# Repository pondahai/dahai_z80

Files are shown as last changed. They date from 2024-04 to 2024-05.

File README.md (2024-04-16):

# dahai_z80  
## 快照  screenshot  
螢幕擷取畫面 2024-04-11 163721

螢幕擷取畫面 2024-04-11 163736

螢幕擷取畫面 2024-04-11 163752


## 參考來源  reference  
Z80微電腦製作，劉秋良，欣大出版  


4晶片的結合Z80與arduino的專案  
https://hackaday.io/project/19000-a-4-4ics-z80-homemade-computer-on-breadboard/details

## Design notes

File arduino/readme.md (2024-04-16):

這一隻arduino程式僅能在uno上執行  
因為用到底層暫存器的存取  

程式主要利用了攔截z80執行週期的方式  
將程式碼搬運到板上的SRAM  
隨後arduino放開對z80的控制  
並且利用arduino的內部計時器產生z80所需的時脈信號  
另外arduino也接收了z80的IORQ信號  
當z80程式執行到IN OUT指令時  
arduino可以充當z80系統的串列埠  
於是電腦端就可以透過串列終端機  
與Z80系統進行通訊

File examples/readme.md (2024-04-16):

這裡存放了本z80微電腦系統中預先安裝的幾隻範例程式  
分別是：
1. ABC-80監督程式
2. 圓周率計算程式
3. 迷你監督程式(透過串列埠)
4. BASIC

為了能夠在這一套z80系統中運作  
都有少許的修改  

感謝這些原作者的貢獻  
這是他們的智慧結晶

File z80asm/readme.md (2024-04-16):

這是z80的組譯器  
來自：http://www.trs-80emulators.com/z80asm/  
主要使用方法
```
z80asm.exe 原始碼 -cim
```
結果會產生 .lst 以及二進制檔 .cim  

另外 conv.py 這隻程式是用來把.cim檔轉換成c語言陣列變數格式  
以便用來把程式碼放在arduino程式裡面  
使用方法：
```
python3 conv.py 二進位碼檔.cim
```
他會直接輸出結果到標準輸出  
可以直接在命令列視窗中複製  
或者用轉向指令把結果存成檔案再進行後續處理

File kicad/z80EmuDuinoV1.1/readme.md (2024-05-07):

螢幕擷取畫面 2024-05-07 092956

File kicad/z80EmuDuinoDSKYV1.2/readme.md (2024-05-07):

螢幕擷取畫面 2024-05-07 092819

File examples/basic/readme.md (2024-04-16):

來自：  
http://searle.x10host.com/z80/SimpleZ80.html  
這個網站也是一套Z80微電腦系統  
裡面有用到一套培基語言  
我把它進行修改以符合本Z80系統的運作  
透過串列埠終端機的方式操作

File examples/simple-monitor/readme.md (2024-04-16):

來自：  
[https://github.com/skx/z80-examples/tree/master](https://github.com/skx/z80-examples/blob/master/simple-monitor.z80)

simple-monitor是一個簡易型透過終端機存取的監督程式  
是利用Z80的IN OUT指令對IO埠口讀寫以達到模擬串列埠的效果  
我有修改部分程式以便符合本套Z80微電腦的架構

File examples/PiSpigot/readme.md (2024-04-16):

這隻程式來自：  
https://github.com/GmEsoft/Z80-MBC2_PiSpigot?tab=readme-ov-file  
原本程式是透過IN OUT指令在另一部Z80微電腦上  
以終端機方式呈現程式運作結果  
我做了一些修改才能在這部Z80微電腦上執行

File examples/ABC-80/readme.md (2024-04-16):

這組程式來自書籍
```
書目資訊
書名	Z 80 微電腦入門: 原理與應用程式
作者	劉秋良
出版者	欣大, 1986
```
書中設計了一部Z80微電腦  
並且將運作其中的監督程式原始碼詳列在書中

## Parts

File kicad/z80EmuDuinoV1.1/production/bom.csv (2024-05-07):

Designator | Footprint | Quantity | Value | LCSC Part #
A1 | Arduino_UNO_R3 | 1 | Arduino_UNO_R3
C1, C2, C3, C4 | C_Disc_D5.0mm_W2.5mm_P5.00mm | 4 | 100n
D1 | LED_D5.0mm_Clear | 1 | HALT
H1, H2, H3, H4 | MountingHole_3.2mm_With_Spacer_H10mm | 4 | M3_Hole_With_Spacer_H10mm
J1 | PinHeader_1x08_P2.54mm_Vertical | 1 | PA
J2 | PinHeader_1x08_P2.54mm_Vertical | 1 | PB
J3 | PinHeader_1x08_P2.54mm_Vertical | 1 | PC
J4, J5, J6, J8 | PinSocket_1x08_P2.54mm_Vertical | 4 | Conn_01x08_Socket
J7 | PinSocket_1x03_P2.54mm_Vertical | 1 | DSKY_PWR
JP1 | TestPoint_2Pads_Pitch2.54mm_Drill0.8mm | 1 | 6264 VCC
JP2 | TestPoint_2Pads_Pitch2.54mm_Drill0.8mm | 1 | A17
JP3 | TestPoint_2Pads_Pitch2.54mm_Drill0.8mm | 1 | 62256 A14
JP4 | TestPoint_2Pads_Pitch2.54mm_Drill0.8mm | 1 | 62256 A13
JP5 | TestPoint_2Pads_Pitch2.54mm_Drill0.8mm | 1 | 6264 CE2
R2 | R_Axial_DIN0207_L6.3mm_D2.5mm_P10.16mm_Horizontal | 1 | 330
RN1, RN2, RN3, RN4 | R_Array_SIP9 | 4 | 10k
U1 | DIP-32_W15.24mm | 1 | AS6C4008-55PCN
U10 | DIP-40_W15.24mm_LongPads | 1 | Z80CPU
U11 | DIP-40_W15.24mm | 1 | 8255A
U2 | DIP-32_W7.62mm | 1 | AS6C4008-55PCN
U4 | DIP-14_W7.62mm_LongPads | 1 | 74LS32
U5 | DIP-14_W7.62mm_LongPads | 1 | 74LS00

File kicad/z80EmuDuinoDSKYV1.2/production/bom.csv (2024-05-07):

Designator | Footprint | Quantity | Value | LCSC Part #
BZ1 | Buzzer_TDK_PS1240P02BT_D12.2mm_H6.5mm | 1 | Buzzer
C1 | C_Disc_D5.0mm_W2.5mm_P5.00mm | 1 | 100n
C2, C3, C4 | C_Disc_D5.0mm_W2.5mm_P5.00mm | 3 | 20n
D1 | LED_D5.0mm_Clear | 1 | PC7
J1 | PinSocket_1x08_P2.54mm_Vertical | 1 | PB
J2 | PinSocket_1x08_P2.54mm_Vertical | 1 | PA
J3 | PinSocket_1x08_P2.54mm_Vertical | 1 | PC
J4 | PinSocket_1x08_P2.54mm_Vertical | 1 | KEYPAD
J5 | PinSocket_1x03_P2.54mm_Vertical | 1 | Conn_01x03_Pin
Q1, Q2, Q3, Q4, Q5, Q6 | TO-92_Inline | 6 | 2N3906
Q10, Q11, Q12, Q7, Q8, Q9 | TO-92_Inline | 6 | 2SA1015
R1, R2, R3, R4, R5, R6, R7, R8 | R_Axial_DIN0207_L6.3mm_D2.5mm_P10.16mm_Horizontal | 8 | 220
R10 | R_Axial_DIN0207_L6.3mm_D2.5mm_P10.16mm_Horizontal | 1 | R10
R11 | R_Axial_DIN0207_L6.3mm_D2.5mm_P10.16mm_Horizontal | 1 | R11
R12 | R_Axial_DIN0207_L6.3mm_D2.5mm_P10.16mm_Horizontal | 1 | Rf
R13, R14, R15 | R_Axial_DIN0207_L6.3mm_D2.5mm_P10.16mm_Horizontal | 3 | 10k
R16, R9 | R_Axial_DIN0207_L6.3mm_D2.5mm_P10.16mm_Horizontal | 2 | 330
RN1 | R_Array_SIP9 | 1 | 10k
SW1 | SW_Kailh_Choc_V1 | 1 | RESET
SW10 | SW_Kailh_Choc_V1 | 1 | 8
SW11 | SW_Kailh_Choc_V1 | 1 | 4
SW12 | SW_Kailh_Choc_V1 | 1 | 0
SW13 | SW_Kailh_Choc_V1 | 1 | D
SW14 | SW_Kailh_Choc_V1 | 1 | 9
SW15 | SW_Kailh_Choc_V1 | 1 | 5
SW16 | SW_Kailh_Choc_V1 | 1 | 1
SW17 | SW_Kailh_Choc_V1 | 1 | E
SW18 | SW_Kailh_Choc_V1 | 1 | A
SW19 | SW_Kailh_Choc_V1 | 1 | 6
SW2 | SW_Kailh_Choc_V1 | 1 | TO TAPE
SW20 | SW_Kailh_Choc_V1 | 1 | 2
SW21 | SW_Kailh_Choc_V1 | 1 | F
SW22 | SW_Kailh_Choc_V1 | 1 | B
SW23 | SW_Kailh_Choc_V1 | 1 | 7
SW24 | SW_Kailh_Choc_V1 | 1 | 3
SW3 | SW_Kailh_Choc_V1 | 1 | FROM TAPE
SW4 | SW_Kailh_Choc_V1 | 1 | GO
SW5 | SW_Kailh_Choc_V1 | 1 | ADDR
SW6 | SW_Kailh_Choc_V1 | 1 | DATA
SW7 | SW_Kailh_Choc_V1 | 1 | -
SW8 | SW_Kailh_Choc_V1 | 1 | +
SW9 | SW_Kailh_Choc_V1 | 1 | C
TP1 | PinHeader_1x01_P2.54mm_Vertical | 1 | AUDIO OUT
TP2 | PinHeader_1x01_P2.54mm_Vertical | 1 | AUDIO IN
TP3, TP4 | PinHeader_1x01_P2.54mm_Vertical | 2 | GND
U1, U2 | D1X8K | 2 | D148K
U3 | CA56-12EWA | 1 | CC56-12EWA
U4 | DIP-8_W7.62mm_LongPads | 1 | MCP6002-xP

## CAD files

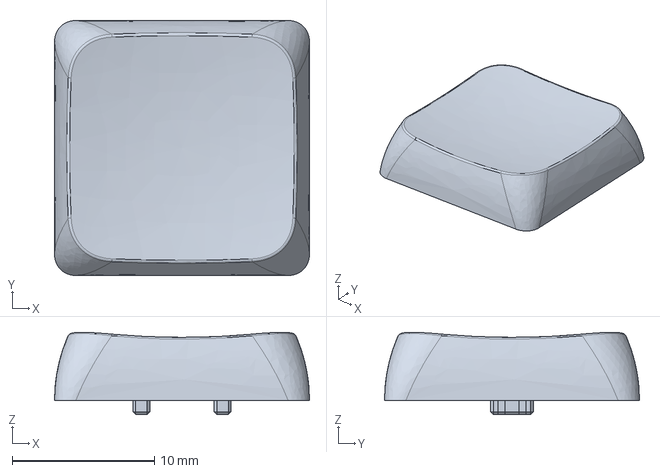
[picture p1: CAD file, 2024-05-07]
kicad/z80EmuDuinoDSKYV1.2/Kailh Choc FunkMonk 1u_black.step
17.9 x 17.9 x 5.78 mm

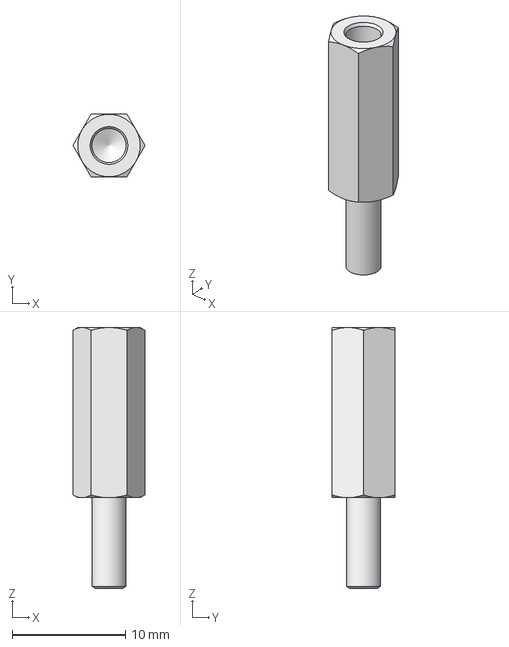
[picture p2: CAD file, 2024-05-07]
kicad/z80EmuDuinoV1.1/hexagonal_spacer_MF_M3_H15_HEX5.5_FTD8_MTL8.step
6.36 x 5.51 x 23.0 mm

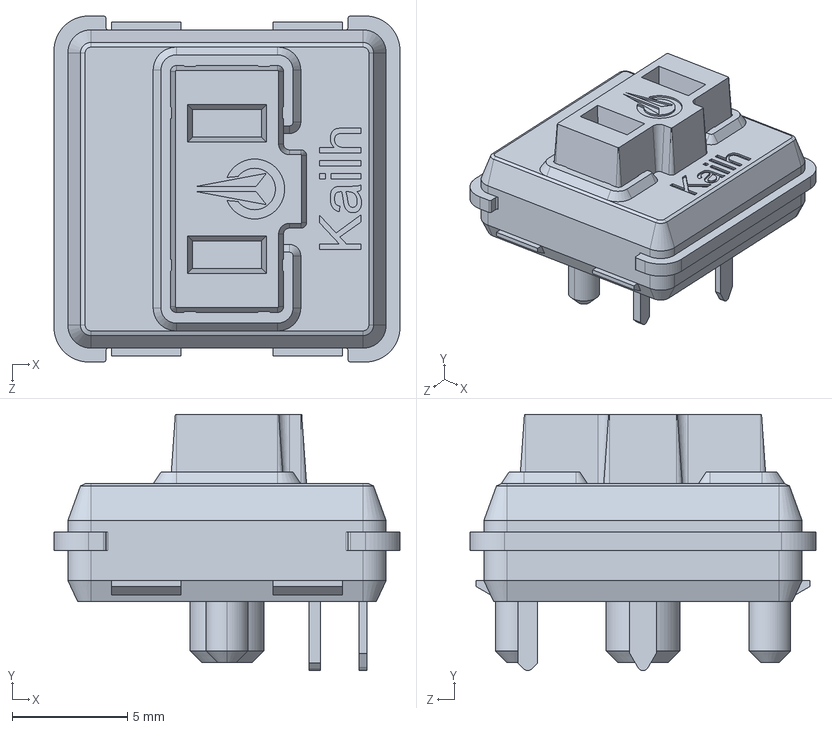
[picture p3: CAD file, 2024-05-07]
kicad/z80EmuDuinoDSKYV1.2/Kailh LP Choc Burnt Orange.STEP
15.0 x 11.1 x 15.0 mm

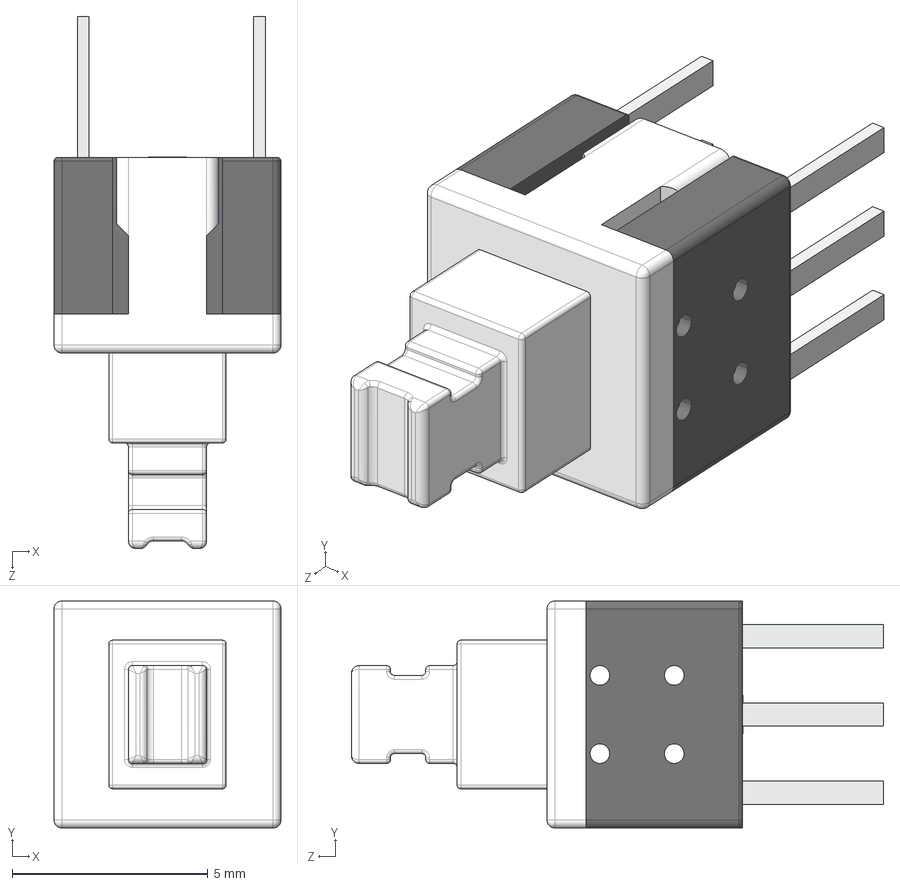
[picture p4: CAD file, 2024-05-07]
kicad/z80EmuDuinoDSKYV1.2/5.8x5.8mmSWITCH.STEP
5.80 x 5.80 x 13.6 mm

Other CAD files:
kicad/z80EmuDuinoDSKYV1.2/Kailh Choc FunkMonk 1u.step

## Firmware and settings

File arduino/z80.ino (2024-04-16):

#include <TimeLib.h>

#define CS328 2
#define nRD 3
#define Z80nRESET 4
#define RESET8255 5
#define nWAITrelease 6
#define ZA0 7
#define nWR 10
#define Z80CLK 11
#define ZA1 12
#define RAMCEINHIBIT 13

const byte intmini[] PROGMEM = {
0xf3, 0xc3, 0xb2, 0x00, 0x00, 0x00, 0x00, 0x00, 0xc3, 0xa2, 0x00, 0x00, 0x00, 0x00, 0x00, 0x00,
0xc3, 0x74, 0x00, 0x00, 0x00, 0x00, 0x00, 0x00, 0xc3, 0xa5, 0x00, 0x00, 0x00, 0x00, 0x00, 0x00,
0x00, 0x00, 0x00, 0x00, 0x00, 0x00, 0x00, 0x00, 0x00, 0x00, 0x00, 0x00, 0x00, 0x00, 0x00, 0x00,
0x00, 0x00, 0x00, 0x00, 0x00, 0x00, 0x00, 0x00, 0x18, 0x00, 0xf5, 0xe5, 0xdb, 0x02, 0xe6, 0x02,
0x28, 0x2d, 0xdb, 0x01, 0xf5, 0x3a, 0x43, 0x20, 0xfe, 0x3f, 0x20, 0x03, 0xf1, 0x18, 0x20, 0x2a,
0x3f, 0x20, 0x23, 0x7d, 0xfe, 0x3f, 0x20, 0x03, 0x21, 0x00, 0x20, 0x22, 0x3f, 0x20, 0xf1, 0x77,
0x3a, 0x43, 0x20, 0x3c, 0x32, 0x43, 0x20, 0xfe, 0x30, 0x38, 0x04, 0x3e, 0xd6, 0xd3, 0x02, 0xe1,
0xf1, 0xfb, 0xed, 0x4d, 0xdb, 0x01, 0xc9, 0x3a, 0x43, 0x20, 0xfe, 0x00, 0x28, 0xf9, 0xe5, 0x2a,
0x41, 0x20, 0x23, 0x7d, 0xfe, 0x3f, 0x20, 0x03, 0x21, 0x00, 0x20, 0xf3, 0x22, 0x41, 0x20, 0x3a,
0x43, 0x20, 0x3d, 0x32, 0x43, 0x20, 0xfe, 0x05, 0x30, 0x04, 0x3e, 0x96, 0xd3, 0x02, 0x7e, 0xfb,
0xe1, 0xc9, 0xd3, 0x01, 0xc9, 0xdb, 0x02, 0xfe, 0x00, 0xc9, 0x7e, 0xb7, 0xc8, 0xcf, 0x23, 0x18,
0xf9, 0xc9, 0x21, 0xed, 0x20, 0xf9, 0x21, 0x00, 0x20, 0x22, 0x3f, 0x20, 0x22, 0x41, 0x20, 0xaf,
0x32, 0x43, 0x20, 0x3e, 0x96, 0xd3, 0x02, 0xed, 0x56, 0xfb, 0x21, 0x03, 0x01, 0xcd, 0xaa, 0x00,
0x3a, 0x44, 0x20, 0xfe, 0x59, 0x20, 0x16, 0x21, 0x1e, 0x01, 0xcd, 0xaa, 0x00, 0xcd, 0x74, 0x00,
0xe6, 0xdf, 0xfe, 0x43, 0x20, 0x0f, 0xcf, 0x3e, 0x0d, 0xcf, 0x3e, 0x0a, 0xcf, 0x3e, 0x59, 0x32,
0x44, 0x20, 0xc3, 0x50, 0x01, 0xfe, 0x57, 0x20, 0xe4, 0xcf, 0x3e, 0x0d, 0xcf, 0x3e, 0x0a, 0xcf,
0xc3, 0x53, 0x01, 0x0c, 0x5a, 0x38, 0x30, 0x20, 0x53, 0x42, 0x43, 0x20, 0x42, 0x79, 0x20, 0x47,
0x72, 0x61, 0x6e, 0x74, 0x20, 0x53, 0x65, 0x61, 0x72, 0x6c, 0x65, 0x0d, 0x0a, 0x00, 0x0d, 0x0a,
0x43, 0x6f, 0x6c, 0x64, 0x20, 0x6f, 0x72, 0x20, 0x77, 0x61, 0x72, 0x6d, 0x20, 0x73, 0x74, 0x61,
0x72, 0x74, 0x20, 0x28, 0x43, 0x20, 0x6f, 0x72, 0x20, 0x57, 0x29, 0x3f, 0x20,

};

const byte basic4[] PROGMEM = {
0xc3, 0x56, 0x01, 0xc3, 0xf4, 0x01, 0xdd, 0x21, 0x00, 0x00, 0xc3, 0x61, 0x01, 0x0c, 0x0a, 0x82,
0x11, 0x21, 0x45, 0x20, 0xf9, 0xc3, 0xa1, 0x1d, 0x11, 0x33, 0x04, 0x06, 0x63, 0x21, 0x45, 0x20,
0x1a, 0x77, 0x23, 0x13, 0x05, 0xc2, 0x70, 0x01, 0xf9, 0xcd, 0x34, 0x06, 0xcd, 0x02, 0x0c, 0x32,
0xef, 0x20, 0x32, 0x3e, 0x21, 0x21, 0x48, 0x02, 0xcd, 0xa0, 0x12, 0xcd, 0x51, 0x06, 0xcd, 0x5a,
0x09, 0xb7, 0xc2, 0xaa, 0x01, 0x21, 0xa2, 0x21, 0x23, 0x7c, 0xb5, 0xca, 0xbc, 0x01, 0x7e, 0x47,
0x2f, 0x77, 0xbe, 0x70, 0xca, 0x98, 0x01, 0xc3, 0xbc, 0x01, 0xcd, 0x26, 0x0a, 0xb7, 0xc2, 0x02,
0x05, 0xeb, 0x2b, 0x3e, 0xd9, 0x46, 0x77, 0xbe, 0x70, 0xc2, 0x85, 0x01, 0x2b, 0x11, 0xa1, 0x21,
0xcd, 0xca, 0x07, 0xda, 0x85, 0x01, 0x11, 0xce, 0xff, 0x22, 0xf4, 0x20, 0x19, 0x22, 0x9f, 0x20,
0xcd, 0x0f, 0x06, 0x2a, 0x9f, 0x20, 0x11, 0xef, 0xff, 0x19, 0x11, 0x3e, 0x21, 0x7d, 0x93, 0x6f,
0x7c, 0x9a, 0x67, 0xe5, 0x21, 0x0c, 0x02, 0xcd, 0xa0, 0x12, 0xe1, 0xcd, 0x43, 0x19, 0x21, 0xfd,
0x01, 0xcd, 0xa0, 0x12, 0x31, 0xab, 0x20, 0xcd, 0x34, 0x06, 0xc3, 0x4d, 0x05, 0x20, 0x42, 0x79,
0x74, 0x65, 0x73, 0x20, 0x66, 0x72, 0x65, 0x65, 0x0d, 0x0a, 0x00, 0x00, 0x5a, 0x38, 0x30, 0x20,
0x42, 0x41, 0x53, 0x49, 0x43, 0x20, 0x56, 0x65, 0x72, 0x20, 0x34, 0x2e, 0x37, 0x62, 0x0d, 0x0a,
0x43, 0x6f, 0x70, 0x79, 0x72, 0x69, 0x67, 0x68, 0x74, 0x20, 0x22, 0x2c, 0x34, 0x30, 0x2c, 0x22,
0x43, 0x29, 0x20, 0x31, 0x39, 0x37, 0x38, 0x20, 0x62, 0x79, 0x20, 0x4d, 0x69, 0x63, 0x72, 0x6f,
0x73, 0x6f, 0x66, 0x74, 0x0d, 0x0a, 0x00, 0x00, 0x4d, 0x65, 0x6d, 0x6f, 0x72, 0x79, 0x20, 0x74,
0x6f, 0x70, 0x00, 0xb8, 0x17, 0x7c, 0x18, 0xce, 0x17, 0x48, 0x20, 0x60, 0x11, 0xe5, 0x14, 0x8e,
0x11, 0x42, 0x1a, 0x21, 0x1b, 0x5d, 0x16, 0x90, 0x1a, 0x96, 0x1b, 0x9c, 0x1b, 0xfd, 0x1b, 0x12,
0x1c, 0x39, 0x15, 0x7d, 0x1c, 0x96, 0x20, 0x12, 0x14, 0x2a, 0x12, 0xac, 0x14, 0x21, 0x14, 0x32,
0x14, 0x9f, 0x1c, 0x32, 0x1d, 0x42, 0x14, 0x72, 0x14, 0x7c, 0x14, 0xc5, 0x4e, 0x44, 0xc6, 0x4f,
0x52, 0xce, 0x45, 0x58, 0x54, 0xc4, 0x41, 0x54, 0x41, 0xc9, 0x4e, 0x50, 0x55, 0x54, 0xc4, 0x49,
0x4d, 0xd2, 0x45, 0x41, 0x44, 0xcc, 0x45, 0x54, 0xc7, 0x4f, 0x54, 0x4f, 0xd2, 0x55, 0x4e, 0xc9,
0x46, 0xd2, 0x45, 0x53, 0x54, 0x4f, 0x52, 0x45, 0xc7, 0x4f, 0x53, 0x55, 0x42, 0xd2, 0x45, 0x54,
0x55, 0x52, 0x4e, 0xd2, 0x45, 0x4d, 0xd3, 0x54, 0x4f, 0x50, 0xcf, 0x55, 0x54, 0xcf, 0x4e, 0xce,
0x55, 0x4c, 0x4c, 0xd7, 0x41, 0x49, 0x54, 0xc4, 0x45, 0x46, 0xd0, 0x4f, 0x4b, 0x45, 0xc4, 0x4f,
0x4b, 0x45, 0xd3, 0x43, 0x52, 0x45, 0x45, 0x4e, 0xcc, 0x49, 0x4e, 0x45, 0x53, 0xc3, 0x4c, 0x53,
0xd7, 0x49, 0x44, 0x54, 0x48, 0xcd, 0x4f, 0x4e, 0x49, 0x54, 0x4f, 0x52, 0xd3, 0x45, 0x54, 0xd2,
0x45, 0x53, 0x45, 0x54, 0xd0, 0x52, 0x49, 0x4e, 0x54, 0xc3, 0x4f, 0x4e, 0x54, 0xcc, 0x49, 0x53,
0x54, 0xc3, 0x4c, 0x45, 0x41, 0x52, 0xc3, 0x4c, 0x4f, 0x41, 0x44, 0xc3, 0x53, 0x41, 0x56, 0x45,
0xce, 0x45, 0x57, 0xd4, 0x41, 0x42, 0x28, 0xd4, 0x4f, 0xc6, 0x4e, 0xd3, 0x50, 0x43, 0x28, 0xd4,
0x48, 0x45, 0x4e, 0xce, 0x4f, 0x54, 0xd3, 0x54, 0x45, 0x50, 0xab, 0xad, 0xaa, 0xaf, 0xde, 0xc1,
0x4e, 0x44, 0xcf, 0x52, 0xbe, 0xbd, 0xbc, 0xd3, 0x47, 0x4e, 0xc9, 0x4e, 0x54, 0xc1, 0x42, 0x53,
0xd5, 0x53, 0x52, 0xc6, 0x52, 0x45, 0xc9, 0x4e, 0x50, 0xd0, 0x4f, 0x53, 0xd3, 0x51, 0x52, 0xd2,
0x4e, 0x44, 0xcc, 0x4f, 0x47, 0xc5, 0x58, 0x50, 0xc3, 0x4f, 0x53, 0xd3, 0x49, 0x4e, 0xd4, 0x41,
0x4e, 0xc1, 0x54, 0x4e, 0xd0, 0x45, 0x45, 0x4b, 0xc4, 0x45, 0x45, 0x4b, 0xd0, 0x4f, 0x49, 0x4e,
0x54, 0xcc, 0x45, 0x4e, 0xd3, 0x54, 0x52, 0x24, 0xd6, 0x41, 0x4c, 0xc1, 0x53, 0x43, 0xc3, 0x48,
0x52, 0x24, 0xc8, 0x45, 0x58, 0x24, 0xc2, 0x49, 0x4e, 0x24, 0xcc, 0x45, 0x46, 0x54, 0x24, 0xd2,
0x49, 0x47, 0x48, 0x54, 0x24, 0xcd, 0x49, 0x44, 0x24, 0x80, 0xa4, 0x09, 0xa1, 0x08, 0x7c, 0x0d,
0xf1, 0x0a, 0x83, 0x0c, 0xb8, 0x0f, 0xb2, 0x0c, 0x08, 0x0b, 0xae, 0x0a, 0x91, 0x0a, 0x80, 0x0b,
0x6a, 0x09, 0x9d, 0x0a, 0xcc, 0x0a, 0xf3, 0x0a, 0xa2, 0x09, 0xf1, 0x14, 0x62, 0x0b, 0xe3, 0x09,
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

};

const byte monitor4[] PROGMEM = {
  // 0x3e, 0x90, 0xd3, 0x83, 0x3e, 0xff, 0xd3, 0x82, 0x3e, 0x00, 0xd3, 0x82, 0xc3, 0x00, 0x00
  // 0x3e, 0x90, 0xd3, 0x83, 0x3e, 0x00, 0xd3, 0x82, 0xdb, 0x80, 0xd3, 0x81, 0xc3, 0x00, 0x00

  0x31, 0x3e, 0x00, 0x3e, 0x3e, 0xd3, 0x01, 0x21, 0x3e, 0x00, 0x36, 0x10, 0xdb, 0x01, 0x77, 0xfe,
  0x10, 0x28, 0x03, 0x23, 0x18, 0xf4, 0x21, 0x3e, 0x00, 0x7e, 0x3e, 0x45, 0xd3, 0x01, 0x3e, 0x52,
  0xd3, 0x01, 0xd3, 0x01, 0x3e, 0x10, 0xd3, 0x01, 0x18, 0xd9, 0x00, 0x00, 0x00, 0x00, 0x00, 0x00,
  0x00, 0x00, 0x00, 0x00, 0x00, 0x00, 0x00, 0x00, 0x00, 0x00, 0x00, 0x00, 0x00, 0x00,

  // 0x3e, 0x31, 0xd3, 0x01, 0x3e, 0x32, 0xd3, 0x01, 0x3e, 0x0d, 0xd3, 0x01,
  // 0xdb, 0x01, 0x00, 0x00, 0x00, 0xd3, 0x01, 0xc3, 0x0c, 0x00, 0x00, 0xc3, 0x0c, 0x00

  // 0xc3, 0x00, 0x20
};
// tiny BASIC
const byte basic[] PROGMEM = {

};

// simple-monitor
const byte simple_monitor[] PROGMEM = {
0x31, 0x17, 0x01, 0x3e, 0x3e, 0xd3, 0x01, 0x21, 0x17, 0x01, 0x36, 0x0a, 0xdb, 0x01, 0x77, 0xd3,
0x01, 0xfe, 0x0d, 0x28, 0x03, 0x23, 0x18, 0xf2, 0x21, 0x17, 0x01, 0x7e, 0xfe, 0x63, 0x28, 0x28,
0xfe, 0x43, 0x28, 0x24, 0xfe, 0x64, 0x28, 0x2c, 0xfe, 0x44, 0x28, 0x28, 0xfe, 0x69, 0x28, 0x53,
0xfe, 0x49, 0x28, 0x4f, 0x3e, 0x45, 0xd3, 0x01, 0x3e, 0x52, 0xd3, 0x01, 0xd3, 0x01, 0x3e, 0x0d,
0xd3, 0x01, 0x3e, 0x0a, 0xd3, 0x01, 0x18, 0xbb, 0x21, 0x18, 0x01, 0xcd, 0xac, 0x00, 0x21, 0x03,
0x00, 0xe5, 0xc5, 0xc9, 0x21, 0x18, 0x01, 0x7e, 0xfe, 0x0d, 0x28, 0x07, 0xcd, 0xac, 0x00, 0xed,
0x43, 0xff, 0x00, 0x2a, 0xff, 0x00, 0xcd, 0xe2, 0x00, 0x06, 0x10, 0x3e, 0x20, 0xd3, 0x01, 0x4e,
0xcd, 0xeb, 0x00, 0x23, 0x10, 0xf5, 0x3e, 0x0d, 0xd3, 0x01, 0x3e, 0x0a, 0xd3, 0x01, 0x22, 0xff,
0x00, 0x18, 0x80, 0x21, 0x18, 0x01, 0x7e, 0xfe, 0x20, 0x28, 0x07, 0xcd, 0xac, 0x00, 0xed, 0x43,
0x01, 0x01, 0x7e, 0x23, 0xfe, 0x20, 0x28, 0xfa, 0xfe, 0x0d, 0x28, 0xe5, 0x2b, 0xcd, 0xb5, 0x00,
0xed, 0x4b, 0x01, 0x01, 0x02, 0x03, 0xed, 0x43, 0x01, 0x01, 0x18, 0xe6, 0xcd, 0xb5, 0x00, 0x47,
0xcd, 0xb5, 0x00, 0x4f, 0xc9, 0x7e, 0xfe, 0x61, 0x38, 0x06, 0xfe, 0x7a, 0x30, 0x02, 0xd6, 0x20,
0xcd, 0xda, 0x00, 0x87, 0x87, 0x87, 0x87, 0x57, 0x23, 0x7e, 0xfe, 0x61, 0x38, 0x06, 0xfe, 0x7a,
0x30, 0x02, 0xd6, 0x20, 0xcd, 0xda, 0x00, 0xb2, 0x23, 0xc9, 0xd6, 0x30, 0xfe, 0x0a, 0xd8, 0xd6,
0x07, 0xc9, 0x4c, 0xcd, 0xeb, 0x00, 0x4d, 0xcd, 0xeb, 0x00, 0xc9, 0x79, 0x1f, 0x1f, 0x1f, 0x1f,
0xcd, 0xf4, 0x00, 0x79, 0xe6, 0x0f, 0xc6, 0x90, 0x27, 0xce, 0x40, 0x27, 0xd3, 0x01, 0xc9, 0x00,
0x00, 0x00, 0x00, 0x00, 0x00, 0x00, 0x00, 0x00, 0x00, 0x00, 0x00, 0x00, 0x00, 0x00, 0x00, 0x00,
0x00, 0x00, 0x00, 0x00, 0x00, 0x00,

};


const byte pi_calcu[] PROGMEM = {
0xf3, 0xc3, 0xd2, 0x01, 0x08, 0x3e, 0x01, 0xd3, 0x00, 0x08, 0xd3, 0x01, 0xc9, 0x7e, 0x23, 0xb7,
0xc8, 0xcd, 0x04, 0x00, 0x18, 0xf7, 0x11, 0xe8, 0x03, 0xcd, 0x2b, 0x00, 0x11, 0x64, 0x00, 0xcd,
0x2b, 0x00, 0x11, 0x0a, 0x00, 0xcd, 0x2b, 0x00, 0x7d, 0x18, 0x08, 0x3e, 0xff, 0x3c, 0xed, 0x52,
0x30, 0xfb, 0x19, 0xc6, 0x30, 0x18, 0xcd, 0x06, 0x0a, 0xcd, 0x40, 0x00, 0xc6, 0x30, 0x18, 0xc4,
0x0e, 0xff, 0x0c, 0x90, 0x30, 0xfc, 0x80, 0x47, 0x79, 0xcd, 0x3c, 0x00, 0x78, 0xc9, 0x23, 0x23,
0x3e, 0x84, 0xd3, 0x00, 0xdb, 0x00, 0x77, 0x2b, 0xdb, 0x00, 0x77, 0x2b, 0xdb, 0x00, 0x77, 0xc9,
0x7e, 0x23, 0xcd, 0x37, 0x00, 0x3e, 0x3a, 0xcd, 0x04, 0x00, 0x7e, 0x23, 0xcd, 0x37, 0x00, 0x3e,
0x3a, 0xcd, 0x04, 0x00, 0x7e, 0xc3, 0x37, 0x00, 0xdb, 0x01, 0xfe, 0xff, 0x28, 0xfa, 0xc9, 0xaf,
0xeb, 0x3c, 0xc8, 0x29, 0x30, 0xfb, 0xcb, 0x1c, 0xcb, 0x1d, 0x44, 0x4d, 0xeb, 0x11, 0x00, 0x00,
0xeb, 0x29, 0xeb, 0xed, 0x42, 0x13, 0x30, 0x02, 0x1b, 0x09, 0xcb, 0x38, 0xcb, 0x19, 0x3d, 0x20,
0xef, 0xeb, 0xc9, 0x06, 0x04, 0xeb, 0xd9, 0xeb, 0x7a, 0xb7, 0x7b, 0xd9, 0x20, 0x09, 0x05, 0xb7,
0x20, 0x05, 0x05, 0xb2, 0x20, 0x01, 0x05, 0x78, 0x87, 0x87, 0x87, 0x47, 0xaf, 0x05, 0x28, 0x09,
0x3c, 0xc8, 0x29, 0xd9, 0xed, 0x6a, 0xd9, 0x30, 0xf4, 0xd9, 0xcb, 0x1c, 0xcb, 0x1d, 0x44, 0x4d,
0xeb, 0x11, 0x00, 0x00, 0xd9, 0xcb, 0x1c, 0xcb, 0x1d, 0x44, 0x4d, 0xeb, 0x11, 0x00, 0x00, 0xeb,
0x29, 0xeb, 0xd9, 0xeb, 0xed, 0x6a, 0xeb, 0xd9, 0xed, 0x42, 0xd9, 0xed, 0x42, 0xd9, 0x13, 0x30,
0x06, 0x1b, 0x09, 0xd9, 0xed, 0x4a, 0xd9, 0xd9, 0xcb, 0x38, 0xcb, 0x19, 0xd9, 0xcb, 0x18, 0xcb,
0x19, 0x3d, 0x20, 0xdb, 0xeb, 0xd9, 0xeb, 0xd9, 0xc9, 0xcd, 0x30, 0x01, 0x21, 0x00, 0x00, 0xd9,
0x21, 0x00, 0x00, 0xd9, 0x3e, 0x10, 0xd9, 0xcb, 0x38, 0xcb, 0x19, 0xd9, 0xcb, 0x18, 0xcb, 0x19,
0xdc, 0x3d, 0x01, 0xeb, 0x29, 0xeb, 0xd9, 0xeb, 0xed, 0x6a, 0xeb, 0xd9, 0x3d, 0x20, 0xe7, 0xc9,
0x44, 0x4d, 0xd9, 0x44, 0x4d, 0xd9, 0xc9, 0x09, 0xd9, 0xed, 0x4a, 0xd9, 0xc9, 0x19, 0xd9, 0xed,
0x5a, 0xd9, 0xc9, 0x29, 0xd9, 0xed, 0x6a, 0xd9, 0xc9, 0xcd, 0x30, 0x01, 0xcd, 0x43, 0x01, 0xcd,
0x43, 0x01, 0xcd, 0x37, 0x01, 0xcd, 0x43, 0x01, 0xc9, 0xcd, 0x49, 0x01, 0xcd, 0xa3, 0x00, 0x01,
0x10, 0x00, 0x09, 0x22, 0x7a, 0x03, 0xeb, 0x2a, 0x78, 0x03, 0xb7, 0xed, 0x52, 0xeb, 0x30, 0x03,
0x2a, 0x78, 0x03, 0x22, 0x7a, 0x03, 0x29, 0x11, 0x8a, 0x03, 0x19, 0xe5, 0xdd, 0xe1, 0x21, 0x00,
0x00, 0x22, 0x7e, 0x03, 0x2a, 0x7e, 0x03, 0xed, 0x5b, 0x7a, 0x03, 0xd9, 0x21, 0x00, 0x00, 0x11,
0x00, 0x00, 0xd9, 0xcd, 0x09, 0x01, 0xeb, 0xdd, 0x6e, 0x00, 0xdd, 0x66, 0x01, 0xd9, 0xeb, 0x21,
0x00, 0x00, 0xd9, 0xcd, 0x49, 0x01, 0xcd, 0x3d, 0x01, 0xe5, 0x2a, 0x7a, 0x03, 0x29, 0x2b, 0xeb,
0xe1, 0xd9, 0x11, 0x00, 0x00, 0xd9, 0xcd, 0xa3, 0x00, 0x22, 0x7e, 0x03, 0xdd, 0x73, 0x00, 0xdd,
0x72, 0x01, 0xdd, 0x2b, 0xdd, 0x2b, 0x2a, 0x7a, 0x03, 0x2b, 0x22, 0x7a, 0x03, 0x7c, 0xb5, 0x20,
0xb3, 0xc9, 0x21, 0x2d, 0x03, 0xcd, 0x0d, 0x00, 0x21, 0x87, 0x03, 0xcd, 0x4e, 0x00, 0xfd, 0x21,
0x76, 0x03, 0x21, 0x32, 0x00, 0x23, 0x22, 0x76, 0x03, 0x11, 0x03, 0x00, 0xd9, 0x21, 0x00, 0x00,
0x11, 0x00, 0x00, 0xd9, 0xcd, 0x49, 0x01, 0xcd, 0xa3, 0x00, 0x22, 0x78, 0x03, 0x23, 0x44, 0x4d,
0x29, 0x11, 0x8a, 0x03, 0x19, 0xd9, 0x21, 0x00, 0x00, 0x39, 0xd9, 0xf9, 0x11, 0x02, 0x00, 0xd5,
0x0b, 0x78, 0xb1, 0x20, 0xfa, 0xd9, 0xf9, 0xaf, 0xfd, 0x77, 0x0a, 0xfd, 0x77, 0x0b, 0xfd, 0x36,
0x0e, 0x0a, 0xfd, 0x36, 0x0d, 0x06, 0xfd, 0x36, 0x0c, 0x2e, 0x21, 0x00, 0x00, 0x22, 0x7c, 0x03,
0x2b, 0x22, 0x85, 0x03, 0x2a, 0x7c, 0x03, 0xeb, 0x2a, 0x76, 0x03, 0xb7, 0xed, 0x52, 0x11, 0x03,
0x00, 0xd9, 0x21, 0x00, 0x00, 0x11, 0x00, 0x00, 0xd9, 0xcd, 0x59, 0x01, 0x2a, 0x7e, 0x03, 0x11,
0x0a, 0x00, 0xcd, 0x7f, 0x00, 0xed, 0x53, 0x8c, 0x03, 0x7d, 0xfe, 0x09, 0x20, 0x05, 0xfd, 0x34,
0x0a, 0x18, 0x3f, 0xfe, 0x0a, 0x20, 0x1c, 0xfd, 0x7e, 0x0b, 0xfd, 0x36, 0x0b, 0x00, 0x3c, 0xcd,
0xee, 0x02, 0xfd, 0x7e, 0x0a, 0xb7, 0x28, 0x09, 0xaf, 0xcd, 0xee, 0x02, 0xfd, 0x35, 0x0a, 0x20,
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

};
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
void loop() {
  // put your main code here, to run repeatedly:
  // delay(000);

  // digitalWrite(Z80CLK, HIGH); /*delay(000);*/ digitalWrite(Z80CLK, LOW);
  /*delay(000);*/
  // Serial.println();
  // CS328 and nWR
  if (((PIND & B00000100) == B00000000) && ((PINB & B00000100) == B00000000)) {

    // delay(1);
    int receive_char;
    // A0 == 0 A1 == 0
    if (((PIND & B10000000) == B00000000) && ((PINB & B00010000) == B00000000)) {
      delay(1);
      receive_char = (PINC & 0x3f | ((PINB & 0x03) << 6));
      if (receive_char == 0x84) {
        cmd_gettime = 1;
        // Serial.println("0x84");
      }
      // delay(1000);
      // digitalWrite(nWAITrelease, LOW);
      // stop timer
      TCCR2A = 0;
      TCCR2B = 0;
      Z80CLKSTROBE;
      PORTD = PORTD & ~B01000000;  // nWAIT release
      Z80CLKSTROBE;                // Tw
      Z80CLKSTROBE;                // T3

      // fetch cycle
      Z80CLKSTROBE;  // T1
      Z80CLKSTROBE;  // T2
      Z80CLKSTROBE;  // T3
      Z80CLKSTROBE;  // T4

      // while((PIND&B00000100) == B00000000);
      // while((PINB&B00000100) == B00000000);
      // digitalWrite(nWAITrelease, HIGH);
      PORTD = PORTD | B01000000;


      // delay(2);
      // restart timer
      TCCR2A = _BV(COM2A0) | _BV(COM2B1) | _BV(WGM21) | _BV(WGM20);
      TCCR2B = _BV(WGM22) | _BV(CS20);
    } // A0 == 0 A1 == 0
    // if(digitalRead(ZA0)==0 && digitalRead(ZA1)==0){
    // A0 == 1 A1 == 0
    else if (((PIND & B10000000) == B10000000) && ((PINB & B00010000) == B00000000)) {
      delay(1);
      receive_char = (PINC & 0x3f | ((PINB & 0x03) << 6));
      // Serial.print(receive_char, HEX); Serial.print(" ");


      Serial.write(receive_char);  // Serial.println();

      // delay(1000);
      // digitalWrite(nWAITrelease, LOW);
      // stop timer
      TCCR2A = 0;
      TCCR2B = 0;
      Z80CLKSTROBE;
      PORTD = PORTD & ~B01000000;  // nWAIT release
      Z80CLKSTROBE;                // Tw
      Z80CLKSTROBE;                // T3

      // fetch cycle
      Z80CLKSTROBE;  // T1
      Z80CLKSTROBE;  // T2
      Z80CLKSTROBE;  // T3
      Z80CLKSTROBE;  // T4

      // digitalWrite(nWAITrelease, HIGH);
      PORTD = PORTD | B01000000;


      // delay(2);
      // restart timer
      TCCR2A = _BV(COM2A0) | _BV(COM2B1) | _BV(WGM21) | _BV(WGM20);
      TCCR2B = _BV(WGM22) | _BV(CS20);
    } // A0 == 1 A1 == 0
    else
    {
      // delay(1);
      TCCR2A = 0;
      TCCR2B = 0;
      Z80CLKSTROBE;
      PORTD = PORTD & ~B01000000;  // nWAIT release
      Z80CLKSTROBE;                // Tw
      Z80CLKSTROBE;                // T3

      // fetch cycle
      Z80CLKSTROBE;  // T1
      Z80CLKSTROBE;  // T2
      Z80CLKSTROBE;  // T3
      Z80CLKSTROBE;  // T4

      PORTD = PORTD | B01000000;

      TCCR2A = _BV(COM2A0) | _BV(COM2B1) | _BV(WGM21) | _BV(WGM20);
      TCCR2B = _BV(WGM22) | _BV(CS20);

    }
  }  // IOWrite

  // CS328 and nRD
  if (((PIND & B00000100) == B00000000) && ((PIND & B00001000) == B00000000)) {

    // if(digitalRead(ZA0)==1 && digitalRead(ZA1)==0){

    // delayMicroseconds(10);
    // A0 == 0 A1 == 0
    if ((((PIND & B10000000) == B00000000) && ((PINB & B00010000) == B00000000)) && (cmd_gettime > 0)) {

        int dat;
        if (cmd_gettime == 1) {
          dat = second();
          cmd_gettime = 2;
        }
        else if (cmd_gettime == 2) {
          dat = minute();
          cmd_gettime = 3;
        }
        else if (cmd_gettime == 3) {
          dat = hour();
          cmd_gettime = 0;
        }

        TCCR2A = 0;
        TCCR2B = 0;
        Z80CLKSTROBE;
        PORTD = PORTD & ~B01000000;  // nWAIT release
        Z80CLKSTROBE;                // Tw
        SETDATABUSOUT((byte)dat);

        Z80CLKSTROBE;  // T3

        SETDATABUSIN;  // change databus direction

        // fetch cycle
        Z80CLKSTROBE;  // T1
        Z80CLKSTROBE;  // T2
        Z80CLKSTROBE;  // T3
        Z80CLKSTROBE;  // T4

        // digitalWrite(nWAITrelease, HIGH);
        PORTD = PORTD | B01000000;

        // restart timer
        TCCR2A = _BV(COM2A0) | _BV(COM2B1) | _BV(WGM21) | _BV(WGM20);
        TCCR2B = _BV(WGM22) | _BV(CS20);

    }
    // if(digitalRead(ZA0)==0 && digitalRead(ZA1)==0){
    // A0 == 1 A1 == 0
    else if (((PIND & B10000000) == B10000000) && ((PINB & B00010000) == B00000000)) {
      // incomingByte = 0xff;
      if (Serial.available() > 0) {
        int incomingByte = 0;

        // if (UCSR0A & _BV(RXC0)) {
        incomingByte = Serial.read();
        // incomingByte = UDR0 ;//
        // Serial.println(incomingByte, HEX);

        // stop timer
        TCCR2A = 0;
        TCCR2B = 0;
        Z80CLKSTROBE;
        PORTD = PORTD & ~B01000000;  // nWAIT release
        Z80CLKSTROBE;                // Tw
        SETDATABUSOUT(incomingByte);

        Z80CLKSTROBE;  // T3

        SETDATABUSIN;  // change databus direction

        // fetch cycle
        Z80CLKSTROBE;  // T1
        Z80CLKSTROBE;  // T2
        Z80CLKSTROBE;  // T3
        Z80CLKSTROBE;  // T4

        PORTD = PORTD | B01000000;

        // restart timer
        TCCR2A = _BV(COM2A0) | _BV(COM2B1) | _BV(WGM21) | _BV(WGM20);
        TCCR2B = _BV(WGM22) | _BV(CS20);
      }



    }  // A0 ==1 A1 == 0
    // A0 == 0 A1 == 1
    else if (((PIND & B10000000) == B00000000) && ((PINB & B00010000) == B00010000)) {
      int incomingByte = 0;
      if (Serial.available() > 0) {
        incomingByte = 0xff;
      }else{
        incomingByte = 0x00;
      }
        // stop timer
        TCCR2A = 0;
        TCCR2B = 0;
        Z80CLKSTROBE;
        PORTD = PORTD & ~B01000000;  // nWAIT release
        Z80CLKSTROBE;                // Tw
        SETDATABUSOUT(incomingByte);

        Z80CLKSTROBE;  // T3

        SETDATABUSIN;  // change databus direction

        // fetch cycle
        Z80CLKSTROBE;  // T1
        Z80CLKSTROBE;  // T2
        Z80CLKSTROBE;  // T3
        Z80CLKSTROBE;  // T4

        PORTD = PORTD | B01000000;

        // restart timer
        TCCR2A = _BV(COM2A0) | _BV(COM2B1) | _BV(WGM21) | _BV(WGM20);
        TCCR2B = _BV(WGM22) | _BV(CS20);            
    } // A0 == 0 A1 == 1
    else{
        // stop timer
        TCCR2A = 0;
        TCCR2B = 0;
        Z80CLKSTROBE;
        PORTD = PORTD & ~B01000000;  // nWAIT release
        Z80CLKSTROBE;                // Tw


        Z80CLKSTROBE;  // T3

        SETDATABUSIN;  // change databus direction

        // fetch cycle
        Z80CLKSTROBE;  // T1
        Z80CLKSTROBE;  // T2
        Z80CLKSTROBE;  // T3
        Z80CLKSTROBE;  // T4

        PORTD = PORTD | B01000000;

        // restart timer
        TCCR2A = _BV(COM2A0) | _BV(COM2B1) | _BV(WGM21) | _BV(WGM20);
        TCCR2B = _BV(WGM22) | _BV(CS20);            

    }
  }    // IORead
}

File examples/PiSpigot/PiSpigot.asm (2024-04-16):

;=============================================================================
;	Spigot algorithm to compute PI
;=============================================================================
;
;	Build:
;		zmac PiSpigot.asm --od PiSpigot --oo cim,lst -c -s -g
;   Convert:
;       python3 conv.py PiSpigot/PiSpigot.cim > PiSpigot.c
;	ZMAC: 8080/Z-80 Cross-Assembler for Windows
;		http://48k.ca/zmac.html
;=============================================================================

;-----------------------------------------------------------------------------
; 	Title
$TITLE	MACRO
	DB	'Pi Spigot - Ver:1.20 - Dec-2019'
	ENDM

;-----------------------------------------------------------------------------
; 	Settings
DEBUG	EQU	0			; Debug mode
NDIGITS	EQU	50			; Number of digits to compute (9674 max)

;-----------------------------------------------------------------------------

CR	EQU	0DH			; Carriage Return
LF	EQU	0AH			; Line Feed

;-----------------------------------------------------------------------------
;	Macro to break in emulator
$BREAK	MACRO
	IF	DEBUG
	DB	0EDH,0F5H		; Emulator $BREAK opcode
	ENDIF
	ENDM
					;

;-----------------------------------------------------------------------------
;	IPL entry
	ORG	0000H

BOOT	DI				; No interrupts
	JP	SPIGOT			;

;-----------------------------------------------------------------------------
;	Send one char to the terminal
PUTCH	EX	AF,AF'			; Save char to A'
	LD	A,1			; IOS:SERIAL_TX opcode
	OUT	(0),A			; send it
	EX	AF,AF'			; restore char in A
	OUT	(1),A			; Send it
	RET				; Done

;-----------------------------------------------------------------------------
;	Send a null-terminated string to the terminal
PUTS	LD	A,(HL)			; get char from string
	INC	HL			; bump ptr
	OR	A			; NULL terminator ?
	RET	Z			; Return if yes
	CALL	PUTCH			; Send char to terminal
	JR	PUTS			; Loop again

;-----------------------------------------------------------------------------
;	Display HL in decimal
PUTHL4:	LD	DE,1000			;
	CALL	PUT1HL			; Display thousands
	LD	DE,100			;
	CALL	PUT1HL			; Display hundreds
	LD	DE,10			;
	CALL	PUT1HL			; Display tens
	LD	A,L			;
	JR	PUTHL1			; Display units
PUT1HL	LD	A,0FFH			; Init counter
PUT1HL1	INC	A			; Inc counter
	SBC	HL,DE			; Try subtract
	JR	NC,PUT1HL1		; Loop while OK
	ADD	HL,DE			; Revert subtract
PUTHL1	ADD	A,'0'			; Adjust for ASCII digit
	JR	PUTCH			; Display it

;-----------------------------------------------------------------------------
;	Display A in decimal
PUTA2:	LD	B,10			;
	CALL	PUT1A			; Display tens
PUTA1:	ADD	A,'0'			; Adjust for ASCII digit
	JR	PUTCH			; Display units
PUT1A:	LD	C,0FFH			; Init counter
PUT1A1:	INC	C			; Inc counter
	SUB	A,B			; Try subtract
	JR	NC,PUT1A1		; Loop while OK
	ADD	A,B			; Revert subtract
	LD	B,A			; Save
	LD	A,C			; Get digit
	CALL	PUTA1			; Display it
	LD	A,B			; Restore
	RET				; Done

;-----------------------------------------------------------------------------
;	Read Time
READTIME:
	INC	HL
	INC	HL
	LD	A,84H			; IOS:OPCODE DATETIME
	OUT	(0),A			; Send opcode
	IN	A,(0)			; Read seconds
	LD	(HL),A			; Save
	DEC	HL			;
	IN	A,(0)			; Read minutes
	LD	(HL),A			; Save
	DEC	HL			;
	IN	A,(0)			; Read hours
	LD	(HL),A			; Save
	RET				; Done


;-----------------------------------------------------------------------------
;	Display Time
PUTTIME	LD	A,(HL)			; Get hours
	INC	HL
	CALL	PUTA2			; Display hours
	LD	A,':'			;
	CALL	PUTCH			; Display sep
	LD	A,(HL)			; Get mintues
	INC	HL
	CALL	PUTA2			; Display minutes
	LD	A,':'			;
	CALL	PUTCH			; Display sep
	LD	A,(HL)			; Get seconds
	JP	PUTA2			; Display seconds

;-----------------------------------------------------------------------------
;	Wait for a keypress from the terminal
WAITKI	IN	A,(1)			; Get char from terminal
	CP	0FFH			; No char ?
	JR	Z,WAITKI		; Loop if yes
	RET				; Done


;-----------------------------------------------------------------------------
;	Div HL by DE
DIVHLDE:
;	Scale divisor
	XOR	A			; Init loop counter
	EX	DE,HL			; Divisor to HL
DIVL1	INC	A			; Inc counter
	RET	Z			; Overflow: return
	ADD	HL,HL			; Shift left divisor
	JR	NC,DIVL1		; Loop while not past left bound
	RR	H			; Restore scaled divisor
	RR	L			;
	LD	B,H			; Scaled Divisor to BC
	LD	C,L			;
	EX	DE,HL			; Dividend to HL
	LD	DE,0			; Clear quotient
DIVL2:	EX	DE,HL			; Shift left quotient
	ADD	HL,HL			;
	EX	DE,HL			;
	SBC	HL,BC			; Try to subtract divisor from dividend (C is cleared)
	INC	DE			; Try to Add 1 to quotient
	JR	NC,DIVJ2		; If OK, go
	DEC	DE			; Cancel addition to quotient
	ADD	HL,BC			; Cancel subtraction
DIVJ2:	SRL	B			; Shift right divisor
	RR	C			;
	DEC	A			; Dec loop counter
	JR	NZ,DIVL2		; Continue while counter > 0
	EX	DE,HL			; Quotient to HL, remainder to DE
	RET				; Done

;-----------------------------------------------------------------------------
;	Long Div HL by DE
LDIVHLDE:
;	Scale divisor
	LD	B,4			; Non-null dividend byte counter
	EX	DE,HL			; Divisor to HL, low word
	EXX				;
	EX	DE,HL			; idem, high word
	LD	A,D			; Get dividend high byte (3)
	OR	A			; Check it
	LD	A,E			; Get dividend next byte (2)
	EXX				;
	JR	NZ,LDIVJ0		; Go if divid high byte is not null
	DEC	B			; dec byte counter
	OR	A			; Check divid next byte (2)
	JR	NZ,LDIVJ0		; Go if divid next byte (2) is not null
	DEC	B			; dec byte counter
	OR	D			; Check divid next byte (1)
	JR	NZ,LDIVJ0		; Go if divid next byte (1) is not null
	DEC	B			; dec byte counter
LDIVJ0	LD	A,B			; mult byte counter by 8
	ADD	A,A			;
	ADD	A,A			;
	ADD	A,A			;
	LD	B,A			;
	XOR	A			; Init loop counter
LDIVL1	DEC	B			; Dec byte counter
	JR	Z,LDIVJ1		; exit loop when zero
	INC	A			; Inc counter
	RET	Z			; Overflow: return

	ADD	HL,HL			; Shift left divisor, low word
	EXX				;
	ADC	HL,HL			; Idem, high word
	EXX				;

	JR	NC,LDIVL1		; Loop while not past left bound

LDIVJ1:	EXX				;
	RR	H			; Restore scaled divisor, high word
	RR	L			;
	LD	B,H			; Scaled divisor to BC, high word
	LD	C,L			;
	EX	DE,HL			; Dividend to HL, high word
	LD	DE,0			; Clear quotient, high word
	EXX				;
	RR	H			; Restore scaled divisor, low word
	RR	L			;
	LD	B,H			; Scaled divisor to BC, low word
	LD	C,L			;
	EX	DE,HL			; Dividend to HL, low word
	LD	DE,0			; Clear quotient, low word

LDIVL2:	EX	DE,HL			; Shift left quotient, high word
	ADD	HL,HL			;
	EX	DE,HL			;
	EXX				;
	EX	DE,HL			; Idem, high word
	ADC	HL,HL			;
	EX	DE,HL			;
	EXX				;

	SBC	HL,BC			; Try to subtract divisor from dividend, low word (C is cleared)
	EXX
	SBC	HL,BC			; Idem, high word
	EXX

	INC	DE			; Try to Add 1 to quotient
	JR	NC,LDIVJ2		; If OK, go
	DEC	DE			; Cancel addition to quotient

	ADD	HL,BC			; Cancel subtraction, low word
	EXX				;
	ADC	HL,BC			; Idem, high word
	EXX				;

LDIVJ2:	EXX				;
	SRL	B			; Shift right divisor, high word
	RR	C			;
	EXX				;
	RR	B			; Idem, low word
	RR	C			;

	DEC	A			; Dec loop counter
	JR	NZ,LDIVL2		; Continue while counter > 0

	EX	DE,HL			; Quotient to HL, remainder to DE, low word
	EXX				;
	EX	DE,HL			; idem, high word
	EXX				;

	RET				; Done
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
